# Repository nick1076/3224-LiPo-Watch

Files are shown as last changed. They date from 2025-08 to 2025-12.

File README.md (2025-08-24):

# 3224 LiPo Watch

This device is a small wrist watch rechargeable via USB-C that displays the time on a small 0.49" OLED display when woken by the user. The device's time can be configured by the user using two buttons (TICK and SET) and features a high-accuracy RTC IC to accurately keep track of the time. The device is run and managed by an Atmel ATtiny3224 microcontroller.

# Parts List

Here is a link to the DigiKey parts list: https://www.digikey.com/en/mylists/list/SETVN3EHG2

## General Documentation

*LED Indicators*

Red - BUILTIN
Blue - Programming Mode
Yellow - Charging (Actively, battery under full capacity)
Green - Power (USB // 3V3 {3V3 if debug switch pulled}) // Done charging (Battery at full capacity, 4.2V across terminals of LiPo expected)

Visible to user:
Yellow (for charging info)
Green (for complete charging)

*Testpoints*

Front:
EXT // 5V0 (External VCC, 5V Expected)
3V3 (Buck converted 3.3V, 3.3V Expected)
USB // 5V0 (USB-C Sourced VCC, 5V Expected)
Ground (x4, mounting holes)

Back:
BAT + (LiPo Battery Positive Terminal, 3.2V to 4.2V Expected)
BAT - (LiPo Battery Negative Terminal, Ground Expected)
Ground (x2)

*Switches // Buttons*

Front:
WAKE / TICK - Push Button on right side - wakes watch, ticks time value in set mode
SET - Push Button on left side - puts watch into set mode and sets current time digit to displayed value

Back:
RTC RST - Push Button on right middle - resets RTC IC (U4)
DEBUG INDICATORS - Slide Switch - enables debug indicator LEDs on board when turned on (Drains LiPo battery in some cases, so best to be off when packaged and not testing)

*Headers*

P1 (PROG - Programming Header)
1 - UPDI - UPDI line from programmer
2 - GND - Ground line from programmer
P2 (UART - UART Header)
1 - TXD - MCU TX
2 - RXD - MCU RX
3 - GND - Ground line from FTDI

# V1 Design

The V1 design featured a rounded PCB with a 0.49" OLED display, 64x32 pixels.

# V2 Design

Due to the 0.49" OLED failing to work properly with the 3224 MCU, the board had to be redesigned to host a larger 128x64 pixel OLED display, turning into a more square-like yet rounded PCB.

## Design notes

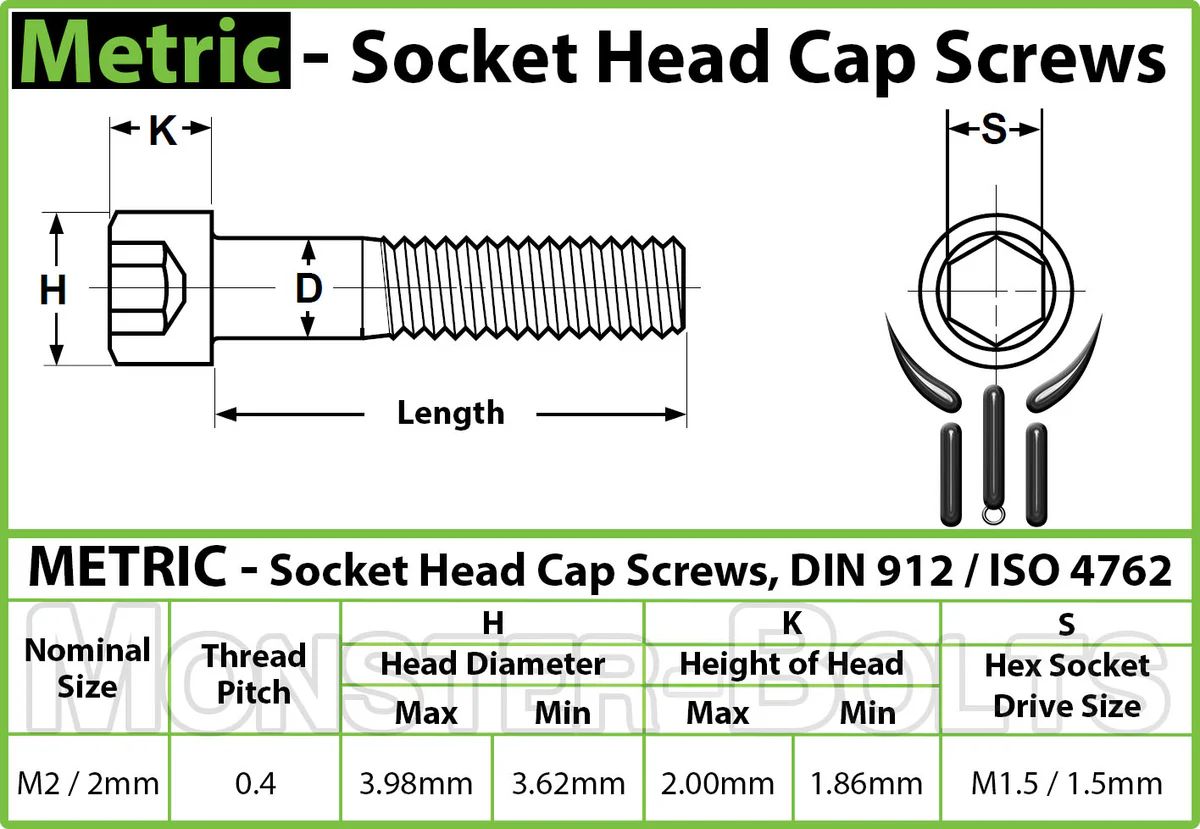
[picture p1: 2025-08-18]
Casing/M2 Bolt Specs.webp

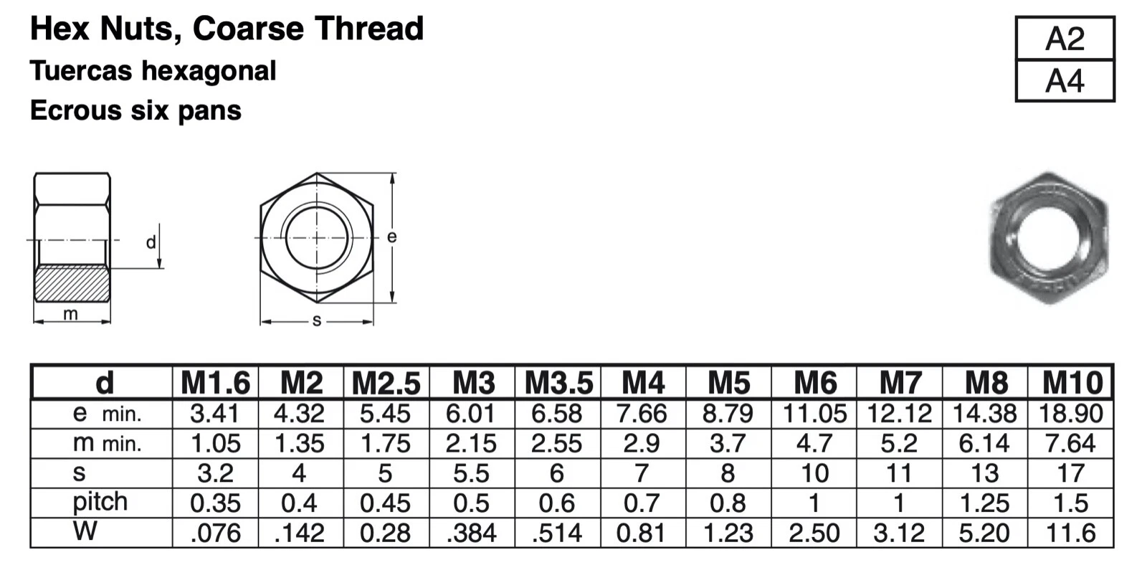
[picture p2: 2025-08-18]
Casing/M2 Nut Specs.webp

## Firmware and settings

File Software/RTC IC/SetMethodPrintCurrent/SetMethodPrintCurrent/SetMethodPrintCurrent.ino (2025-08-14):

// now.pde
// Prints a snapshot of the current date and time along with the UNIX time
// Modified by Andy Wickert from the JeeLabs / Ladyada RTC library examples
// 5/15/11

#include <Wire.h>
#include <DS3231.h>

DS3231 myRTC;

bool century = false;
bool h12Flag;
bool pmFlag;
byte alarmDay, alarmHour, alarmMinute, alarmSecond, alarmBits;
bool alarmDy, alarmH12Flag, alarmPmFlag;

void setup () {
    Serial.begin(57600);
    Wire.begin();
    delay(500);
    SetClock();
    Serial.println("Nano Ready!");
}

void SetClock(){
    myRTC.setClockMode(false);  // set to 24h
    //setClockMode(true); // set to 12h
    
    myRTC.setYear(25);
    myRTC.setMonth(8);
    myRTC.setDate(14);
    myRTC.setDoW(4);
    myRTC.setHour(14);
    myRTC.setMinute(22);
    myRTC.setSecond(45);

    /*
    // Test of alarm functions
    // set A1 to one minute past the time we just set the clock
    // on current day of week.
    myRTC.setA1Time(dOW, hour, minute+1, second, 0x0, true,
                    false, false);
    // set A2 to two minutes past, on current day of month.
    myRTC.setA2Time(date, hour, minute+2, 0x0, false, false,
                    false);
    // Turn on both alarms, with external interrupt
    myRTC.turnOnAlarm(1);
    myRTC.turnOnAlarm(2);*/
}

void loop () {

    
    delay(1000);/*
  Serial.print(myRTC.getYear(), DEC);
  Serial.print(' ');
  
  // then the month
  Serial.print(myRTC.getMonth(century), DEC);
  Serial.print(" ");
  
  // then the date
  Serial.print(myRTC.getDate(), DEC);
  Serial.print(" ");
  
  // and the day of the week
  Serial.print(myRTC.getDoW(), DEC);
  Serial.print(" ");
  */
  // Finally the hour, minute, and second
  if (myRTC.getHour(h12Flag, pmFlag) > 12){
    Serial.print(myRTC.getHour(h12Flag, pmFlag)-12, DEC);
  }
  else{
    Serial.print(myRTC.getHour(h12Flag, pmFlag), DEC);
  }
  Serial.print(":");
  Serial.print(myRTC.getMinute(), DEC);
  Serial.print(":");
  Serial.print(myRTC.getSecond(), DEC);
 
  // Add AM/PM indicator
  if (h12Flag) {
    if (pmFlag) {
      Serial.print(" PM ");
    } else {
      Serial.print(" AM ");
    }
  } else {
    Serial.println(" 24h");
  }

  /*
 
  // Display the temperature
  Serial.print("T=");
  Serial.print(myRTC.getTemperature(), 2);
  
  // Tell whether the time is (likely to be) valid
  if (myRTC.oscillatorCheck()) {
    Serial.print(" O+");
  } else {
    Serial.print(" O-");
  }
 
  // Indicate whether an alarm went off
  if (myRTC.checkIfAlarm(1)) {
    Serial.print(" A1!");
  }
 
  if (myRTC.checkIfAlarm(2)) {
    Serial.print(" A2!");
  }
 
  // New line on display
  Serial.println();
  
  // Display Alarm 1 information
  Serial.print("Alarm 1: ");
  myRTC.getA1Time(alarmDay, alarmHour, alarmMinute, alarmSecond, alarmBits, alarmDy, alarmH12Flag, alarmPmFlag);
  Serial.print(alarmDay, DEC);
  if (alarmDy) {
    Serial.print(" DoW");
  } else {
    Serial.print(" Date");
  }
  Serial.print(' ');
  Serial.print(alarmHour, DEC);
  Serial.print(' ');
  Serial.print(alarmMinute, DEC);
  Serial.print(' ');
  Serial.print(alarmSecond, DEC);
  Serial.print(' ');
  if (alarmH12Flag) {
    if (alarmPmFlag) {
      Serial.print("pm ");
    } else {
      Serial.print("am ");
    }
  }
  if (myRTC.checkAlarmEnabled(1)) {
    Serial.print("enabled");
  }
  Serial.println();
 
  // Display Alarm 2 information
  Serial.print("Alarm 2: ");
  myRTC.getA2Time(alarmDay, alarmHour, alarmMinute, alarmBits, alarmDy, alarmH12Flag, alarmPmFlag);
  Serial.print(alarmDay, DEC);
  if (alarmDy) {
    Serial.print(" DoW");
  } else {
    Serial.print(" Date");
  }
  Serial.print(" ");
  Serial.print(alarmHour, DEC);
  Serial.print(" ");
  Serial.print(alarmMinute, DEC);
  Serial.print(" ");
  if (alarmH12Flag) {
    if (alarmPmFlag) {
      Serial.print("pm");
    } else {
      Serial.print("am");
    }
  }
  if (myRTC.checkAlarmEnabled(2)) {
    Serial.print("enabled");
  }
 
  // display alarm bits
  Serial.println();
  Serial.print("Alarm bits: ");
  Serial.println(alarmBits, BIN);

  Serial.println();
  */
}

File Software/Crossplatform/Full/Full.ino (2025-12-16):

//Headers
#include <Adafruit_GFX.h> //Graphics library for display
#include <Adafruit_SSD1306.h> //Display library
#include <Wire.h> //For custom i2c
#include <DS3231.h> //Library for RTC IC

//Vars
#define SCREEN_WIDTH 128 //Width of display used
#define SCREEN_HEIGHT 64 //Height of display used
#define WAKE_INPUT 1 //Wake Button Input
#define SET_INPUT 9 //Set Button Input
#define IND_ENA_INPUT 10 //Set Button Input
#define LED_BUILTIN_OUTPUT 8 //Set Button Input

bool awake = false; //Tracks if screen is currently awake
bool setMode = false; //Tracks if watch is currently in SET mode (for setting time)
bool initialized = false; //Tracks if screen initialized properly

Adafruit_SSD1306 display(SCREEN_WIDTH, SCREEN_HEIGHT, &Wire, -1); //Screen
DS3231 myRTC; //RTC IC

//RTC Vars
bool century = false;
bool h12Flag;
bool pmFlag;
byte alarmDay, alarmHour, alarmMinute, alarmSecond, alarmBits;
bool alarmDy, alarmH12Flag, alarmPmFlag;

//Other Watch control variables
byte dispCounter = 0;
int tick = 0;
int parallelTick = 0;
byte setIndex = 0;

byte currentSetHour = 0;
byte currentSetMinute = 0;

//Time (in increments of 10ms) between each uptick in current number
int setMode_increaseTimeCooldown = 5;

//Time (in increments of 10ms) between each index (hour to minute to exiting set mode)
int setMode_switchSetIndexCooldown = 8;

//Pixel offset of displayed data if hour time is double digits
int xDualDecimalHourOffset = -10;

void setup () {
    Serial.begin(57600);
    Wire.begin();

    pinMode(WAKE_INPUT, INPUT_PULLUP);
    pinMode(SET_INPUT, INPUT_PULLUP);
    pinMode(IND_ENA_INPUT, INPUT_PULLUP);
    pinMode(LED_BUILTIN_OUTPUT, INPUT_PULLUP);

    delay(100);
    
    digitalWrite(LED_BUILTIN_OUTPUT, HIGH);
    delay(100);
    digitalWrite(LED_BUILTIN_OUTPUT, LOW);
    delay(100);
    digitalWrite(LED_BUILTIN_OUTPUT, HIGH);
    delay(100);
    digitalWrite(LED_BUILTIN_OUTPUT, LOW);

    delay(100);
    
    Serial.println("Initializing...");

    //Check if display has failed to begin
    if(!display.begin(SSD1306_SWITCHCAPVCC, 0x3C)) {
      Serial.println(F("SSD1306 allocation failed"));
      return;
    }
    else{
      //Otherwise display has started correctly
      Serial.println("Initialized.");
      initialized = true;
      Clear();
    }

    delay(500);

    SetClock(12, 0);
    Serial.println("Watch Ready!");
}

//Display info on watch screen
void DisplayText(String text, int x, int y, int size, bool clear = true){
  if (clear){
    display.clearDisplay();
  }
  display.setTextSize(size);
  display.setTextColor(WHITE);
  display.setCursor(x, y);
  display.println(text);
  display.display(); 
}

//Display time on OLED
void DisplayTime(int x, int y, int size, bool showDots, bool updateDisplay = true){
  display.clearDisplay();
  display.setTextSize(size);
  display.setTextColor(WHITE);

  if (myRTC.getHour(h12Flag, pmFlag) > 12){
    //Check if double digit hour, if so, move cursor X to the left some more
    if (myRTC.getHour(h12Flag, pmFlag)-12>9){
      display.setCursor(x+xDualDecimalHourOffset, y);
    }
    else{
      display.setCursor(x, y);
    }
  }
  else{
    if (myRTC.getHour(h12Flag, pmFlag) > 9){
      display.setCursor(x+xDualDecimalHourOffset, y);
    }
    else{
      display.setCursor(x, y);
    }
  }

  if (myRTC.getHour(h12Flag, pmFlag) > 12){
    display.print(myRTC.getHour(h12Flag, pmFlag)-12, DEC);
  }
  else{
    display.print(myRTC.getHour(h12Flag, pmFlag), DEC);
  }
  if (showDots){
    display.print(":");
  }
  else{
    display.print(" ");
  }
  if (myRTC.getMinute() < 10){
    display.print("0");
    display.println(myRTC.getMinute(), DEC);
  }
  else{
    display.println(myRTC.getMinute(), DEC);
  }

  if (!updateDisplay) { return; }
  display.display(); 
}

void loop () {
  delay(10); //10 ms delay per tick
  tick++;
  bool isDebugMode = false;

  if (digitalRead(IND_ENA_INPUT) == LOW){
    isDebugMode=true;
  }
  else{
    isDebugMode=false;
  }

  if (!isDebugMode){
    digitalWrite(LED_BUILTIN_OUTPUT, LOW);
  }

  if (digitalRead(SET_INPUT) == LOW && !setMode){
    setMode = true;
    setIndex = 0;
    parallelTick = 0;
    tick=0;
    currentSetHour = myRTC.getHour(h12Flag, pmFlag);
    currentSetMinute = myRTC.getMinute();
    return;
  }

  if (setMode){
    DisplayTime(30, 20, 3, true, false);

    int xOffset = 0;

    if (myRTC.getHour(h12Flag, pmFlag) > 12){
      //Check if double digit hour, if so, move cursor X to the left some more
      if (myRTC.getHour(h12Flag, pmFlag)-12>9){
        xOffset+=xDualDecimalHourOffset;
      }
    }
    else{
      if (myRTC.getHour(h12Flag, pmFlag) > 9){
        xOffset+=xDualDecimalHourOffset;
      }
    }
    
    if (setIndex == 0){
      DisplayText("H", 50+xOffset, 50, 2, false);
    }
    else{
      DisplayText("M", 50+xOffset, 50, 2, false);
    }
    
    parallelTick++;
    awake = false;
    if (digitalRead(WAKE_INPUT) == LOW && parallelTick >= setMode_increaseTimeCooldown){
      parallelTick = 0;

      //Hour slot
      if (setIndex == 0){
        currentSetHour++;
        
        if (currentSetHour > 24){
          currentSetHour = 1;
        }
        
        myRTC.setHour(currentSetHour);
      }

      //Minutes slot
      else if (setIndex == 1){
        currentSetMinute++;
        
        if (currentSetMinute > 59){
          currentSetMinute = 0;
        }
        
        myRTC.setMinute(currentSetMinute);
      }
    }

    //If user hits set button again after cooldown
    if (digitalRead(SET_INPUT) == LOW && tick >= setMode_switchSetIndexCooldown){
      tick=0;
      setIndex++;

      //Exit set mode
      if (setIndex >= 2){
        tick = 0;
        Clear();
        setMode = false;
        delay(500);
        return;
      }
    }
  }

  if (setMode){
    return;
  }
  
  if (!awake && digitalRead(WAKE_INPUT) == LOW){
    dispCounter = 0;
    awake = true;
  }
  else if (!awake){
    Clear();
    return;
  }
  else if (awake){
    if (dispCounter >= 10){
      awake = false;
      dispCounter = 0;
      Clear();
      return;
    }
  }
  
  if (tick < 50){
    return;
  }
  tick=0;
  
  if (dispCounter % 2 == 0){
    DisplayTime(30, 20, 3, true);
  }
  else{
    DisplayTime(30, 20, 3, false);
  }
  dispCounter++;
  if (dispCounter >= 200){
    dispCounter=0;
  }
  if (myRTC.getHour(h12Flag, pmFlag) > 12){
    Serial.print(myRTC.getHour(h12Flag, pmFlag)-12, DEC);
  }
  else{
    Serial.print(myRTC.getHour(h12Flag, pmFlag), DEC);
  }
  Serial.print(":");
  Serial.print(myRTC.getMinute(), DEC);
  Serial.print(":");
  Serial.print(myRTC.getSecond(), DEC);
 
  // Add AM/PM indicator
  if (h12Flag) {
    if (pmFlag) {
      Serial.print(" PM ");
    } else {
      Serial.print(" AM ");
    }
  } else {
    Serial.println(" 24h");
  }
}
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

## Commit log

2025-06-28 further work
    [Display.SchDoc, LiPo ATtiny Watch.PrjPcb, LiPo BMS.SchDoc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]
2025-06-29 BMS overhaul, indicator rework, pcb layout rework
    [LiPo ATtiny Watch.PrjPcb, LiPo BMS.SchDoc, Microcontroller.SchDoc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]
2025-06-29 Major layout updates
    [LiPo BMS.SchDoc, Microcontroller.SchDoc, PCB.PcbDoc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]
2025-06-30 basic layout finished
    [PCB.PcbDoc]
2025-07-02 Fully checked and prepped schematic & layout, ready for routing
    [Display.SchDoc, LiPo ATtiny Watch.PrjPcb, Microcontroller.SchDoc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]
2025-07-07 Gerbers and parts list
    [PCB.PcbDoc]
2025-07-13 Ready for manufacturing
    [LiPo ATtiny Watch.PrjPcb, Microcontroller.SchDoc, PCB.PcbDoc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]
2025-08-04 rework for mk2 started
    [Display.SchDoc, LiPo BMS.SchDoc, Microcontroller.SchDoc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]
2025-08-05 layout mk2 almost done
    [Microcontroller.SchDoc, PCB.PcbDoc, RTC IC.SchDoc]
2025-08-05 Removal of Mk. 2
    [Display.SchDoc, LiPo ATtiny Watch.PrjPcb, LiPo BMS.SchDoc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]
2025-08-05 Mk. 3
    [Display.SchDoc, LiPo ATtiny Watch.PrjPcb, LiPo BMS.SchDoc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]
2025-08-14 Code development
    [Main.PcbDoc]
2025-08-21 Watch shape redesign (needs fixing)
    [Display.SchDoc, PCB.PcbDoc]
2025-08-24 Board shape and layout for V2 fixed
    [Copy of Amazon OLED Display Module.PcbLib, LiPo BMS.SchDoc, Microcontroller.SchDoc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]
2025-08-24 Schematic organization, further layout, documentation
    [Copy of Amazon OLED Display Module.PcbLib, Display.SchDoc, LiPo ATtiny Watch.PrjPcb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]
2025-08-24 Layout updates & fixes
    [LiPo ATtiny Watch.PrjPcb, Microcontroller.SchDoc, OLED_Library.PcbLib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]
2025-08-28 V2 Layout finished
    [PCB.PcbDoc, RTC IC.SchDoc]
2025-12-16 Bug fixes on hour display and more
    quicker increment and setindex switch time, M and H in set mode, fixed hour time text placement if double digit
    [Full.ino]
